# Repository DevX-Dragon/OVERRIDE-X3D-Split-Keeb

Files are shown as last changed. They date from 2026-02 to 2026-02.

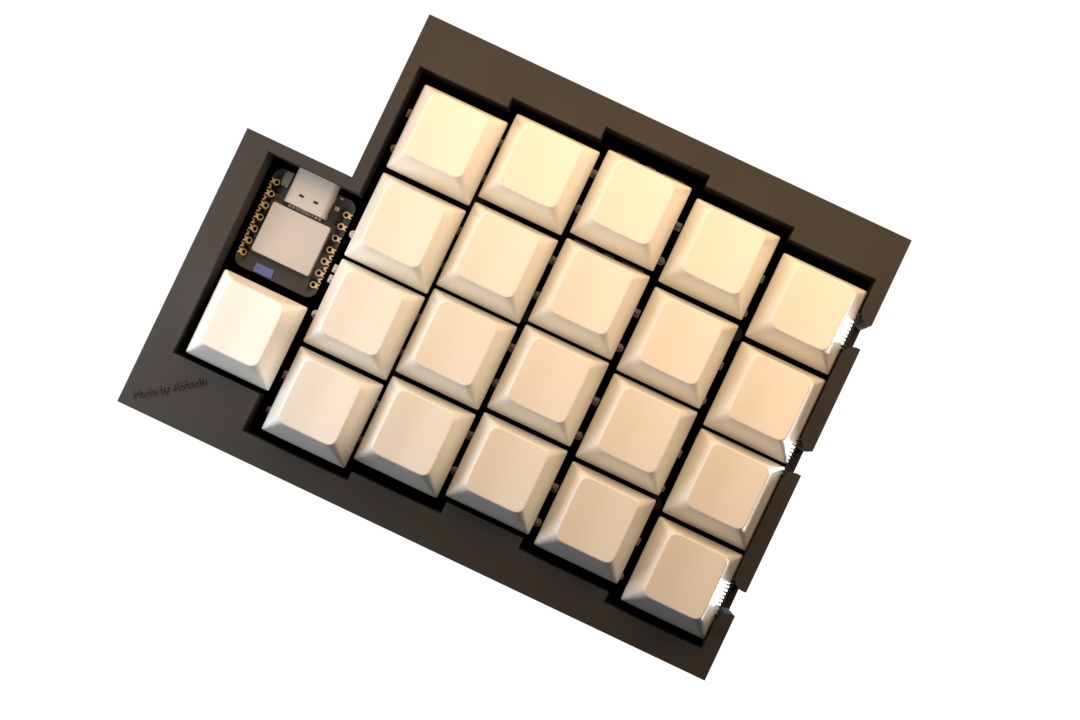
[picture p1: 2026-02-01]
images/LEFT ASSEMBLED .png

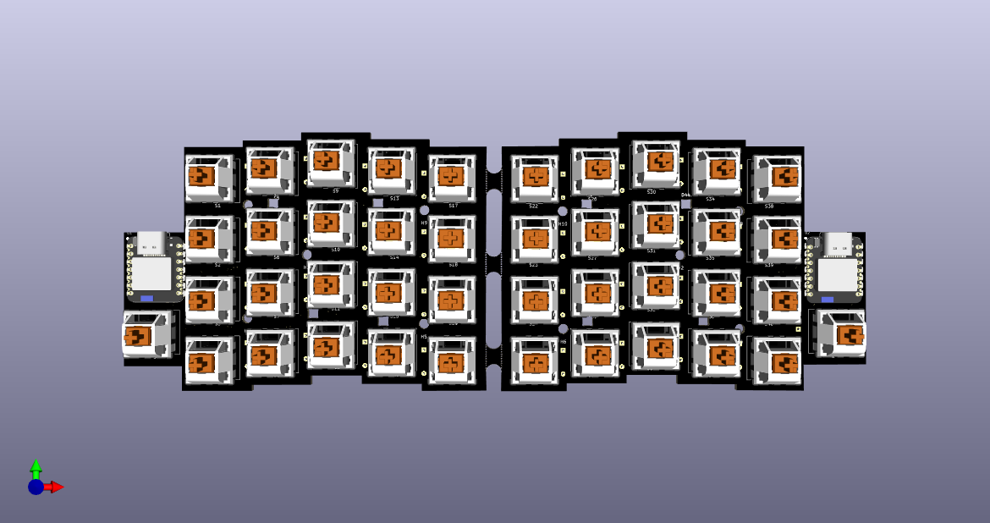
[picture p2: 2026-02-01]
images/3D View Kicad Front.png

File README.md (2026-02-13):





# OVERRIDE-X3D Split Keeb
A split keyboard from-scratch, high-performance wireless split keyboard designed for ergonomic uses.
both assembled

## Layout
Schematics Layout Left Right
PCB Layout

## Renders
#### Assembled Render
both assembled
LEFT ASSEMBLED
RIGHT ASSEMBLED

#### PCB Render
3D View Kicad Front
3D View Kicad Back
3D View Kicad Side

## Firmware
This keyboard runs on **CircuitPython** using the **Adafruit HID library**. Unlike compiled firmware, you can edit your keymap by simply modifying the **code.py** file directly on the keyboard's internal storage.

#### Libraries
To run this firmware, you need the following libraries in your /lib folder:

**adafruit_hid** (For Keyboard and Consumer Control support)

**adafruit_ble** (For wireless Bluetooth connectivity)

## BOM
(note that this is where I purchased from, and some are bought in higher quanities then needed for cheaper prices and some websites are local-only)
| Product Name | Quantity | Source Link | Price |
| :--- | :--- | :--- | :--- |
| 1N4148 | 42 | [Link](https://www.duino.lk/product/x-1n4148-diode-in4148-4148-switching-diode/) | $0.60 |
| SK6812 MINI-E | 8 | [Link](http://www.aliexpress.com/item/1005008308801366.html) | $1.56 |
| 820K Ohms THT Resistor | 2 | [Link](https://www.duino.lk/product/820k-ohm-1-4w-820k-5-carbon-film-resistor/) | $0.30 |
| 1M Ohms THT Ressitor | 4 | [Link](https://www.duino.lk/product/1m-ohm-1-4w-1m-5-carbon-film-resistor/) | $0.30 |
| OUTEMU Red Switches | 42 | [Link](https://share.temu.com/CwgZ9XWDBxB) | $13.74 |
| Milk Theme XDA Key Caps | 42 | [Link](https://www.aliexpress.com/item/1005009136116760.html) | $10.83 |
| 800mAh 3.7V 501845P Battery | 2 | [Link](https://www.duino.lk/product/800mah-3-7v-501845p-lipo-battery/) | $3.00 |
| Seed Studio Seeed XIAO-nRF52840-Sense | 2 | [Link](https://www.aliexpress.com/item/1005007426899386.html) | $43.12 |
| **Total** | | | **$73.45** |

> The reason for using the Seed Studio Seeed XIAO-nRF52840-Sense is becuase thats the only compact MCU which has enough pins for this. The esp32-s3 is another alternative but doesnt have pins to control the LEDs. So I had to go with this. There are no other MCU thats fits in the same size and have the same amount of pins.

## Support
I would love getting financially supported as most of my projects cost alot of money here in Sri Lanka. Even a 1$ is great!

<a href="https://www.buymeacoffee.com/abbadh">
  Buy Me A Coffee
</a>

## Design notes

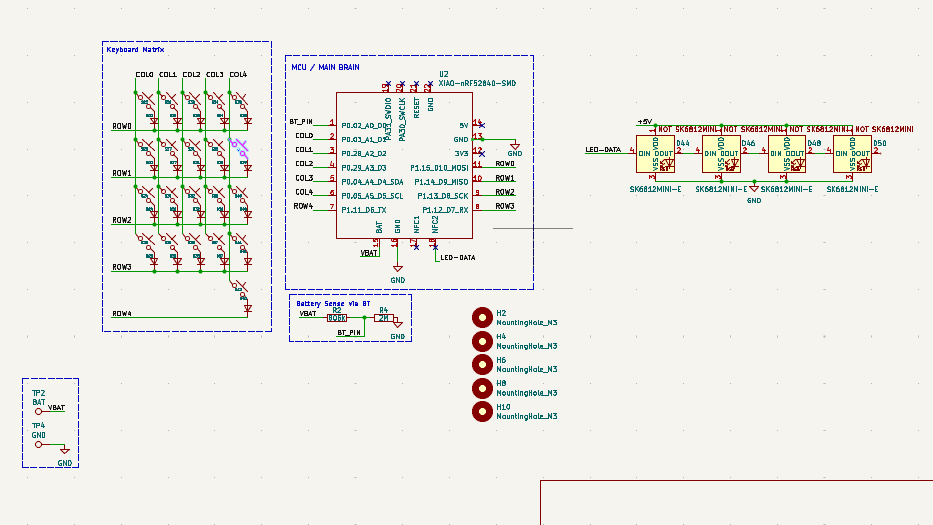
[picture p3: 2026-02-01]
images/Schematics Layout Left Right.png

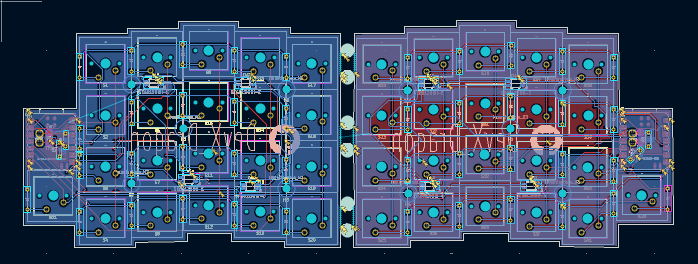
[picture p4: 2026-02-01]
images/PCB Layout.png

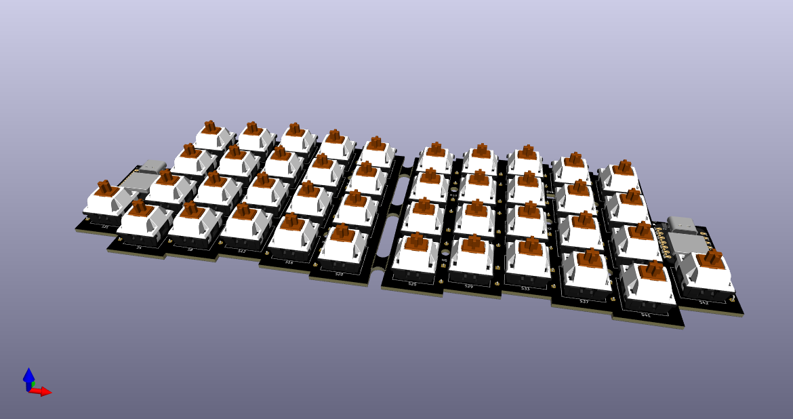
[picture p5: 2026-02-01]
images/3D View Kicad Side.png

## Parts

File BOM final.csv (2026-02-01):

Product Name | Quanity | Source Link | Price | Additional Notes
1N4148 | 42 | https://www.duino.lk/product/x-1n4148-diode-in4148-4148-switching-diode/ | $0.60 | switching diodes ig
SK6812 MINI-E | 8 | www.aliexpress.com/item/1005008308801366.html | $1.56 | I wasn’t able to find anything on TEMU so had to switch to Alie (MOQ - 20)
820K Ohms THT Resistor | 2 | https://www.duino.lk/product/820k-ohm-1-4w-820k-5-carbon-film-resistor/ | $0.30 | wasn't able to find the specific 806K so went with the 820K
1M Ohms THT Ressitor | 4 | https://www.duino.lk/product/1m-ohm-1-4w-1m-5-carbon-film-resistor/ | $0.30 | couldn’t find 2m ohms so got x2 1m and solder them paral
OUTEMU Red Switches | 42 | https://share.temu.com/CwgZ9XWDBxB | $13.74 | I have searched for the cheapest ones and this one has the best value even though its 70 pcs
Milk Theme XDA Key Caps | 42 | https://www.aliexpress.com/item/1005009136116760.html | $10.83 | I didn’t find XDA keycaps for cheap price on TEMU, so had to go with a set on Alie
800mAh 3.7V 501845P Battery | 2 | https://www.duino.lk/product/800mah-3-7v-501845p-lipo-battery/ | $3.00 | I have gone local for this as this will be cheaper
Seed Studio Seeed XIAO-nRF52840-Sense | 2 | https://www.aliexpress.com/item/1005007426899386.html | $43.12 | I specifically need this module cause I have wired the LEDS to the NFC pin. Its possible to unlock those pins as GPIOs
PCB | 5 | https://jlcpcb.com/ | $35.00
3D Printed Cases | 2 | https://duino.lk/ | $5.00
 |  | Shipping Fees (all combined) | $2.00
 |  | Taxes of Aliexpress | $15.00
 |  | Forex Change (Prediction) | $5.00
 |  | Total | $135.45

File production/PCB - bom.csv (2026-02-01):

Designator | Footprint | Quantity | Value | LCSC Part #
D1, D10, D11, D12, D13, D14, D15, D16, D17, D18, D19, D2, D20, D21, D22, D23, D24, D25, D26, D27, D28, D29, D3, D30, D31, D32, D33, D34, D35, D36, D37, D38, D39, D4, D40, D41, D42, D5, D6, D7, D8, D9 | Diode_DO-35 | 42 | ~
D43, D44, D45, D46, D47, D48, D49, D50 | SK6812MINI-E_fixed | 8 | SK6812MINI-E
H1, H10, H2, H3, H4, H5, H6, H7, H8, H9 | MountingHole_3.2mm_M3 | 10 | MountingHole_M3
R1, R2 | R_Axial_DIN0204_L3.6mm_D1.6mm_P5.08mm_Horizontal | 2 | 806k
R3, R4 | R_Axial_DIN0204_L3.6mm_D1.6mm_P5.08mm_Horizontal | 2 | 2M
S1, S10, S11, S12, S13, S14, S15, S16, S17, S18, S19, S2, S20, S21, S22, S23, S24, S25, S26, S27, S28, S29, S3, S30, S31, S32, S33, S34, S35, S36, S37, S38, S39, S4, S40, S41, S42, S5, S6, S7, S8, S9 | MX_PCB_1.00u | 42 | ~
TP1, TP2 | TestPoint_Pad_D2.0mm | 2 | BAT
TP3, TP4 | TestPoint_Pad_D2.0mm | 2 | GND
U1, U2 | modified-XIAO-nRF52840-SMD | 2 | XIAO-nRF52840-SMD

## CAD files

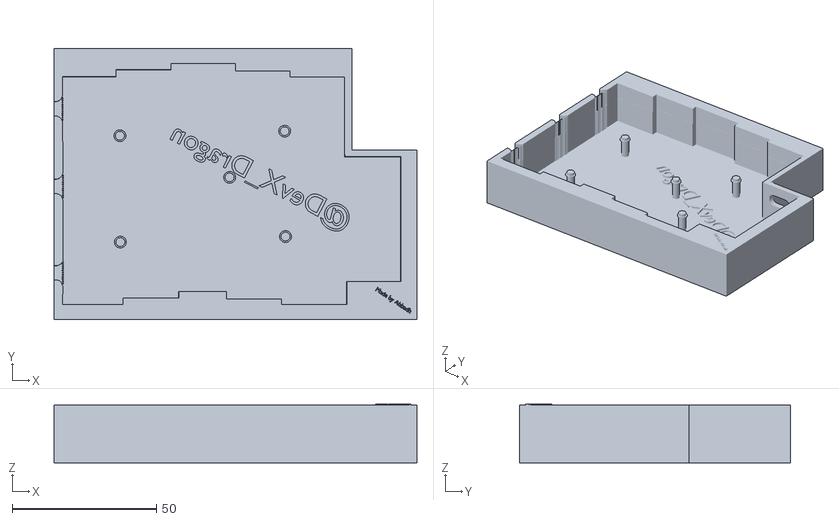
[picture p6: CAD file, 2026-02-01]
3d files/right case.stl
126.0 x 94.0 x 20.3

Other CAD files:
3d files/Right Side Assembled.step
3d files/Left Case Assembled.step
3d files/left case.stl

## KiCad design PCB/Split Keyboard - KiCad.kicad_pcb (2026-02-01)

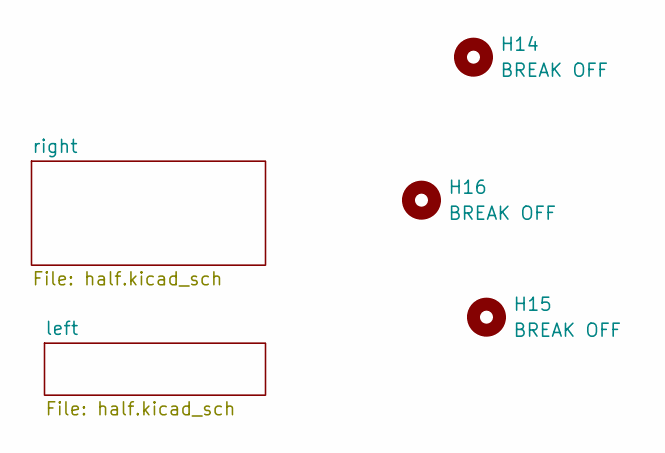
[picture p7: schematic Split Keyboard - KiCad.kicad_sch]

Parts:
H14, H15, H16: BREAK OFF; mouse-bite-5mm-slot

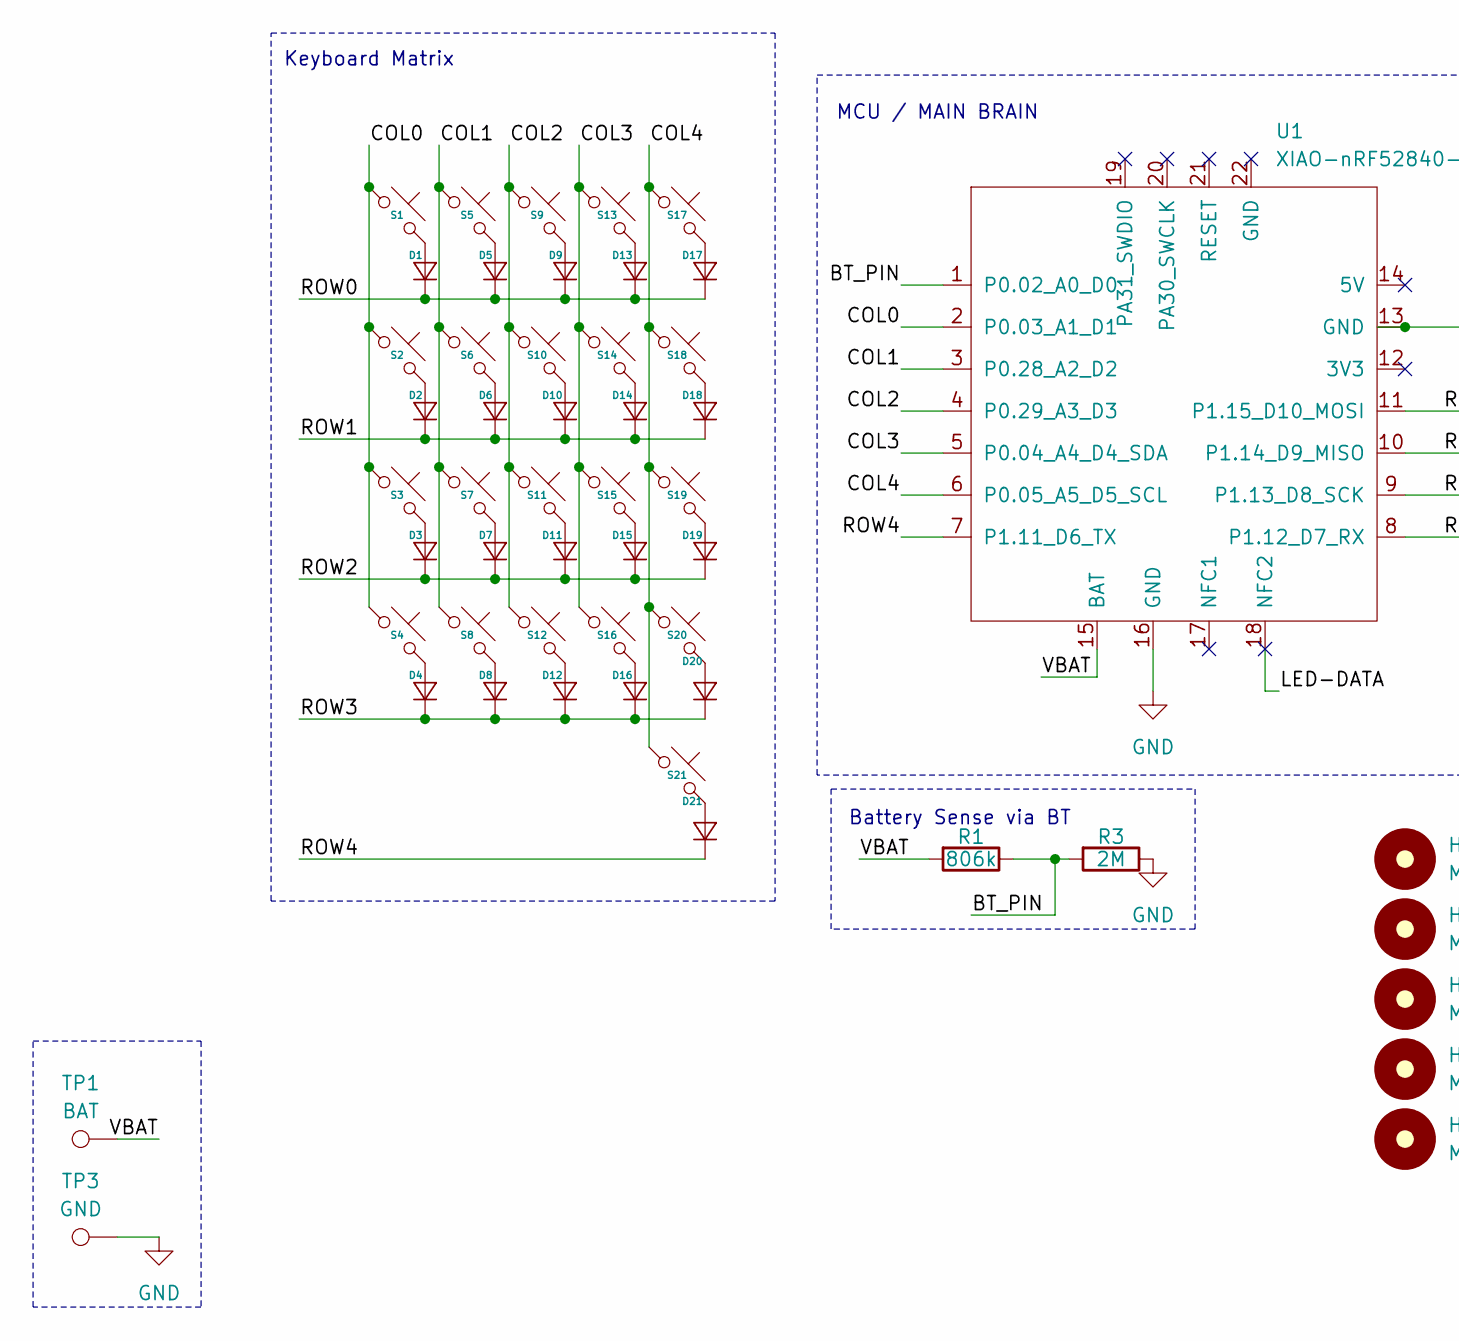
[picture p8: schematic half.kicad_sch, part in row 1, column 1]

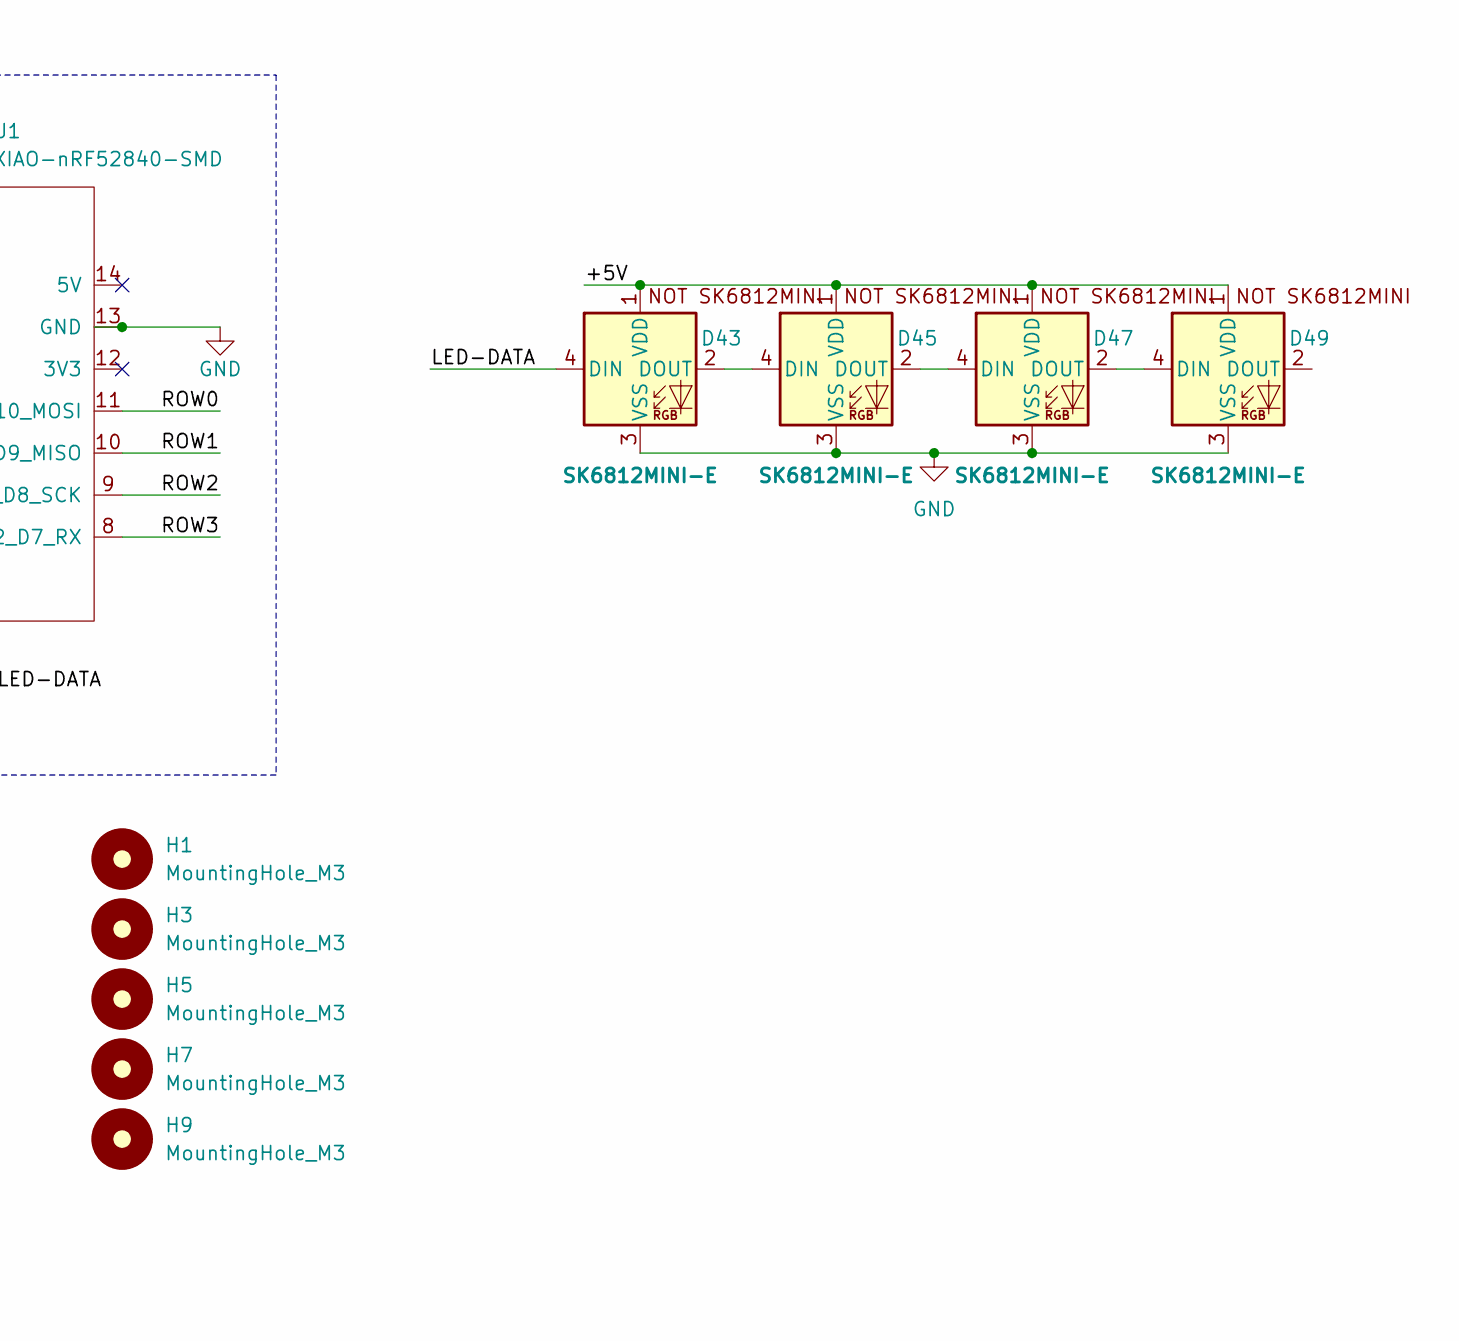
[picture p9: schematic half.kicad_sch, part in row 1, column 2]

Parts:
D1, D2, D3, D4, D5, D6, D7, D8, D9, D10, D11, D12, D13, D14, D15, D16, D17, D18, D19, D20, D21: Diode_DO-35
D43, D45, D47, D49: SK6812MINI-E; SK6812MINI-E_fixed
H1, H3, H5, H7, H9: MountingHole_M3; MountingHole_3.2mm_M3
R1: 806k; R_Axial_DIN0204_L3.6mm_D1.6mm_P5.08mm_Horizontal
R3: 2M; R_Axial_DIN0204_L3.6mm_D1.6mm_P5.08mm_Horizontal
S1, S2, S3, S4, S5, S6, S7, S8, S9, S10, S11, S12, S13, S14, S15, S16, S17, S18, S19, S20, S21: MX_PCB_1.00u
TP1: BAT; TestPoint_Pad_D2.0mm
TP3: GND; TestPoint_Pad_D2.0mm
U1: XIAO-nRF52840-SMD; modified-XIAO-nRF52840-SMD

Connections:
/right/+5V: D43.1 (VDD), D45.1 (VDD), D47.1 (VDD), D49.1 (VDD)
/right/BT_PIN: R1.1, R3.2, U1.1 (P0.02_A0_D0)
/right/COL0: S1.1, S2.1, S3.1, S4.1, U1.2 (P0.03_A1_D1)
/right/COL1: S5.1, S6.1, S7.1, S8.1, U1.3 (P0.28_A2_D2)
/right/COL2: S9.1, S10.1, S11.1, S12.1, U1.4 (P0.29_A3_D3)
/right/COL3: S13.1, S14.1, S15.1, S16.1, U1.5 (P0.04_A4_D4_SDA)
/right/COL4: S17.1, S18.1, S19.1, S20.1, S21.1, U1.6 (P0.05_A5_D5_SCL)
/right/LED-DATA: D43.4 (DIN), U1.18 (NFC2)
/right/ROW0: D1.1 (K), D5.1 (K), D9.1 (K), D13.1 (K), D17.1 (K), U1.11 (P1.15_D10_MOSI)
/right/ROW1: D2.1 (K), D6.1 (K), D10.1 (K), D14.1 (K), D18.1 (K), U1.10 (P1.14_D9_MISO)
/right/ROW2: D3.1 (K), D7.1 (K), D11.1 (K), D15.1 (K), D19.1 (K), U1.9 (P1.13_D8_SCK)
/right/ROW3: D4.1 (K), D8.1 (K), D12.1 (K), D16.1 (K), D20.1 (K), U1.8 (P1.12_D7_RX)
/right/ROW4: D21.1 (K), U1.7 (P1.11_D6_TX)
/right/VBAT: R1.2, TP1.1, U1.15 (BAT)
GND: D43.3 (VSS), D45.3 (VSS), D47.3 (VSS), D49.3 (VSS), R3.1, TP3.1, U1.13 (GND), U1.16 (GND); also elsewhere on the board
unnamed: D1.2 (A), S1.2
unnamed: D2.2 (A), S2.2
unnamed: D3.2 (A), S3.2
unnamed: D4.2 (A), S4.2
unnamed: D5.2 (A), S5.2
unnamed: D6.2 (A), S6.2
unnamed: D7.2 (A), S7.2
unnamed: D8.2 (A), S8.2
unnamed: D9.2 (A), S9.2
unnamed: D10.2 (A), S10.2
unnamed: D11.2 (A), S11.2
unnamed: D12.2 (A), S12.2
unnamed: D13.2 (A), S13.2
unnamed: D14.2 (A), S14.2
unnamed: D15.2 (A), S15.2
unnamed: D16.2 (A), S16.2
unnamed: D17.2 (A), S17.2
unnamed: D18.2 (A), S18.2
unnamed: D19.2 (A), S19.2
unnamed: D20.2 (A), S20.2
unnamed: D21.2 (A), S21.2
unnamed: D43.2 (DOUT), D45.4 (DIN)
unnamed: D45.2 (DOUT), D47.4 (DIN)
unnamed: D47.2 (DOUT), D49.4 (DIN)

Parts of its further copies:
D22, D23, D24, D25, D26, D27, D28, D29, D30, D31, D32, D33, D34, D35, D36, D37, D38, D39, D40, D41, D42: Diode_DO-35
D44, D46, D48, D50: SK6812MINI-E; SK6812MINI-E_fixed
H2, H4, H6, H8, H10: MountingHole_M3; MountingHole_3.2mm_M3
R2: 806k; R_Axial_DIN0204_L3.6mm_D1.6mm_P5.08mm_Horizontal
R4: 2M; R_Axial_DIN0204_L3.6mm_D1.6mm_P5.08mm_Horizontal
S22, S23, S24, S25, S26, S27, S28, S29, S30, S31, S32, S33, S34, S35, S36, S37, S38, S39, S40, S41, S42: MX_PCB_1.00u
TP2: BAT; TestPoint_Pad_D2.0mm
TP4: GND; TestPoint_Pad_D2.0mm
U2: XIAO-nRF52840-SMD; modified-XIAO-nRF52840-SMD

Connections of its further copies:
/left/+5V: D44.1 (VDD), D46.1 (VDD), D48.1 (VDD), D50.1 (VDD)
/left/BT_PIN: R2.1, R4.2, U2.1 (P0.02_A0_D0)
/left/COL0: S22.1, S23.1, S24.1, S25.1, U2.2 (P0.03_A1_D1)
/left/COL1: S26.1, S27.1, S28.1, S29.1, U2.3 (P0.28_A2_D2)
/left/COL2: S30.1, S31.1, S32.1, S33.1, U2.4 (P0.29_A3_D3)
/left/COL3: S34.1, S35.1, S36.1, S37.1, U2.5 (P0.04_A4_D4_SDA)
/left/COL4: S38.1, S39.1, S40.1, S41.1, S42.1, U2.6 (P0.05_A5_D5_SCL)
/left/LED-DATA: D44.4 (DIN), U2.18 (NFC2)
/left/ROW0: D22.1 (K), D26.1 (K), D30.1 (K), D34.1 (K), D38.1 (K), U2.11 (P1.15_D10_MOSI)
/left/ROW1: D23.1 (K), D27.1 (K), D31.1 (K), D35.1 (K), D39.1 (K), U2.10 (P1.14_D9_MISO)
/left/ROW2: D24.1 (K), D28.1 (K), D32.1 (K), D36.1 (K), D40.1 (K), U2.9 (P1.13_D8_SCK)
/left/ROW3: D25.1 (K), D29.1 (K), D33.1 (K), D37.1 (K), D41.1 (K), U2.8 (P1.12_D7_RX)
/left/ROW4: D42.1 (K), U2.7 (P1.11_D6_TX)
/left/VBAT: R2.2, TP2.1, U2.15 (BAT)
GND: D44.3 (VSS), D46.3 (VSS), D48.3 (VSS), D50.3 (VSS), R4.1, TP4.1, U2.13 (GND), U2.16 (GND); also elsewhere on the board
unnamed: D22.2 (A), S22.2
unnamed: D23.2 (A), S23.2
unnamed: D24.2 (A), S24.2
unnamed: D25.2 (A), S25.2
unnamed: D26.2 (A), S26.2
unnamed: D27.2 (A), S27.2
unnamed: D28.2 (A), S28.2
unnamed: D29.2 (A), S29.2
unnamed: D30.2 (A), S30.2
unnamed: D31.2 (A), S31.2
unnamed: D32.2 (A), S32.2
unnamed: D33.2 (A), S33.2
unnamed: D34.2 (A), S34.2
unnamed: D35.2 (A), S35.2
unnamed: D36.2 (A), S36.2
unnamed: D37.2 (A), S37.2
unnamed: D38.2 (A), S38.2
unnamed: D39.2 (A), S39.2
unnamed: D40.2 (A), S40.2
unnamed: D41.2 (A), S41.2
unnamed: D42.2 (A), S42.2
unnamed: D44.2 (DOUT), D46.4 (DIN)
unnamed: D46.2 (DOUT), D48.4 (DIN)
unnamed: D48.2 (DOUT), D50.4 (DIN)

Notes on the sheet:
Keyboard Matrix
MCU / MAIN BRAIN
Battery Sense via BT

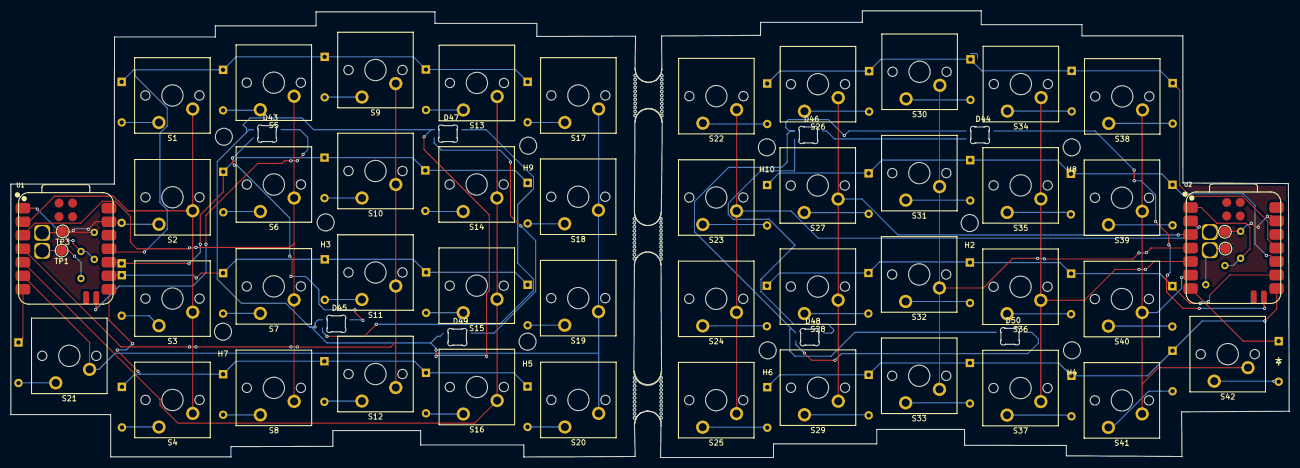
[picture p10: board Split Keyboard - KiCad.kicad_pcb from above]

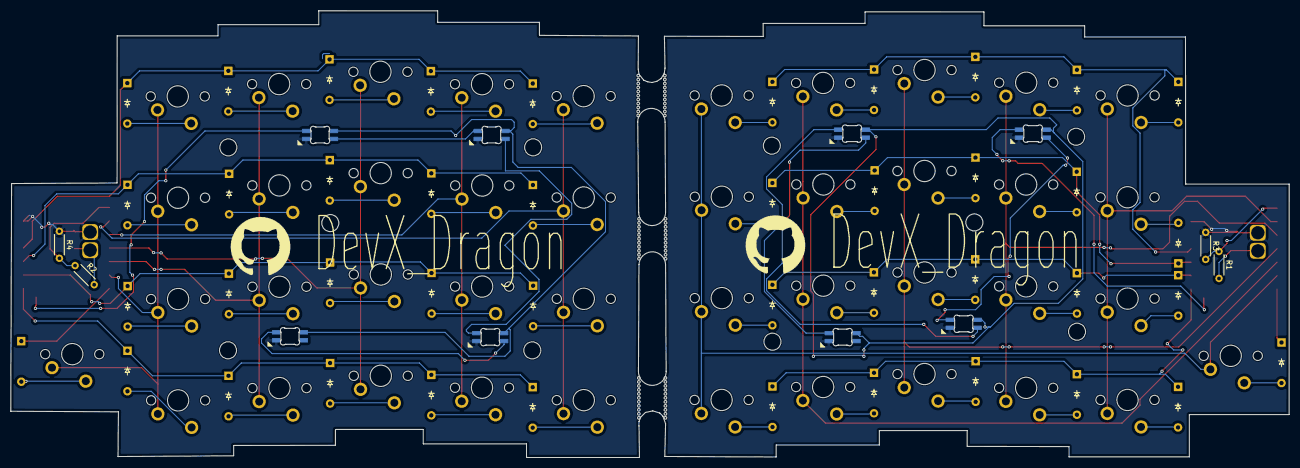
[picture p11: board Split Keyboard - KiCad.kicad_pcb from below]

Board: 2 copper layers, 240.3 x 84.0 mm, 115 parts (45 on the bottom side), 77 nets.

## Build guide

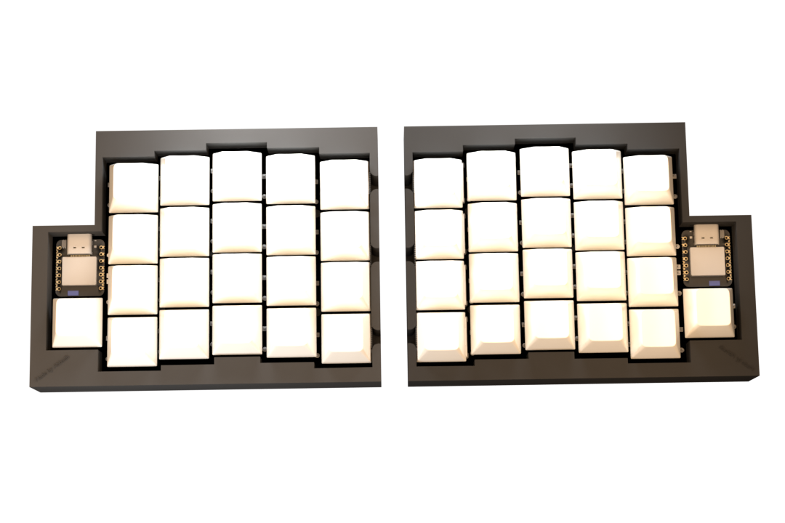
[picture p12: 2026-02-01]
images/both assembled .png

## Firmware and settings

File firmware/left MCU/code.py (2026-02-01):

import board
import keypad
import adafruit_ble
from adafruit_ble.advertising.standard import Advertisement
from adafruit_ble.services.nordic import UARTService

# Hardware Setup
rows = [board.D11, board.D9, board.D8, board.D7]
cols = [board.D1, board.D2, board.D3, board.D4, board.D5]
keys = keypad.KeyMatrix(rows, cols, columns_to_anodes=False)

ble = adafruit_ble.BLERadio()
uart = UARTService()
advertisement = Advertisement()
advertisement.connectable = True
advertisement.short_name = "XIAO_L"

while True:
    ble.start_advertising(advertisement)
    while not ble.connected:
        pass
    ble.stop_advertising()

    while ble.connected:
        event = keys.events.get()
        if event:
            # Send key index and state (1=pressed, 0=released)
            msg = f"{event.key_number},{int(event.pressed)}\n"
            uart.write(msg.encode("utf-8"))

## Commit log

2026-02-01 Adding All
    [PCB - bom.csv, Split Keyboard - KiCad.kicad_pcb, Split Keyboard - KiCad.kicad_sch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]
2026-02-13 Adding assembled preview in step files
    [Left Case Assembled.step, Right Side Assembled.step]
